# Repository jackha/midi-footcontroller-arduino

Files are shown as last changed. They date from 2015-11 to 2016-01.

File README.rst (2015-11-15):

midi-footcontroller-arduino
---------------------------

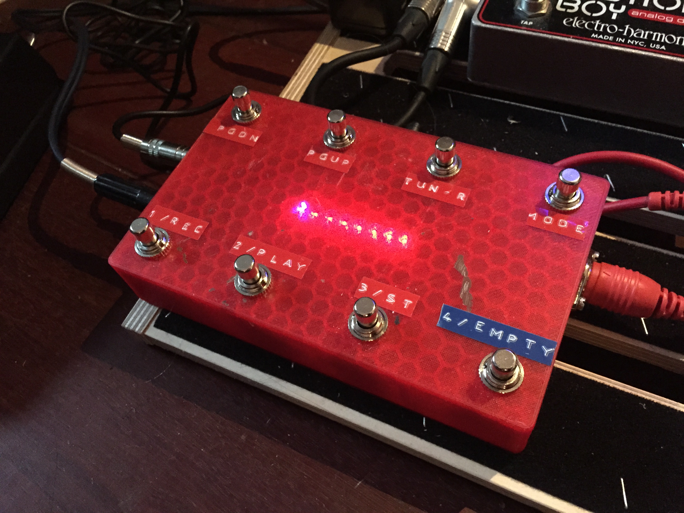
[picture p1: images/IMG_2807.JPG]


License MPL v2.0, originally written by Jack Ha.

I'm using this pedal with an Eventide H9. Awesome fx pedal, but not enough buttons :-)
The foot controller has 2 expression pedal inputs and 8 momentary buttons and was made using an Arduino Uno. 

Preset switching is a pain in the %$#, especially if you also want to tap tempo, adjust volume, use the 'hotknob' as a pedal and use the 'performance' button as well. I know that this is specifically for the H9, but I can imagine you can have the same feeling as well for other gear.

Preset mode:
Page Up, Page Down, Tuner, Mode
Preset 1, Preset 2, Preset 3, Preset 4

Looper mode (didn't use this in the video):
Direction switch, Octave switch, Tuner, Mode
Record, Play, Stop, Empty

media
-----

youtube
=======

https://www.youtube.com/watch?v=iySvyHlC4qQ

https://youtu.be/PKquv8TrxEU

thingiverse
===========

http://www.thingiverse.com/thing:1132912

setup
-----

Make the thing. See Thingiverse.

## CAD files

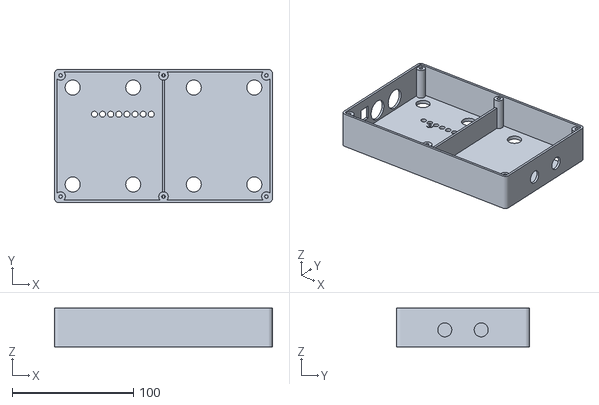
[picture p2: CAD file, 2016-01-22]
openscad/midi-footcontroller-x8.stl
180.0 x 110.0 x 32.0

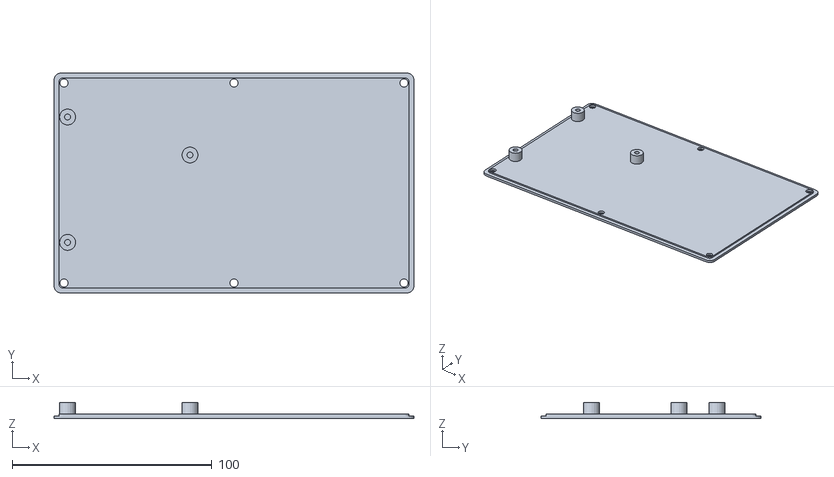
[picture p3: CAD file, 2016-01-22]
openscad/midi-footcontroller-x8-back.stl
180.0 x 110.0 x 8.20

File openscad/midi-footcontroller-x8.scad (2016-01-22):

/*
multiple footswitches, newer version than 'multi-footswitchx'
 
4x2

print with PLA to prevent warping

custom own pcb.
*/

$fn=20;


WALL_THICKNESS = 2;
FRONT_THICKNESS = 3;

BACK_THICKNESS = 1.3;
BACK_THICKNESS_OUTER = 1.0;  // minimum 1

MOUNT_X = 5;
MOUNT_Y = 5;
MOUNT_R_OUTER = 4;
MOUNT_R_INNER = 1.5;

FOOTSWITCH_HOLE_R = 6.25;
FOOTSWITCH_NUM_X = 4;
FOOTSWITCH_NUM_Y = 2;
FOOTSWITCH_SPACING_X = 50;
FOOTSWITCH_SPACING_Y = 80;
FOOTSWITCH_OFFSET_X = 15;
FOOTSWITCH_OFFSET_Y = 15;

WIDTH = 2*FOOTSWITCH_OFFSET_X + (FOOTSWITCH_NUM_X-1)*FOOTSWITCH_SPACING_X;  //180;
HEIGHT = 2*FOOTSWITCH_OFFSET_Y + (FOOTSWITCH_NUM_Y-1)*FOOTSWITCH_SPACING_Y;  // actually depth in our context
DEPTH = 32;  // actually height in our context
ROUNDING_R = 3.5;

PSU_R = 4.1;  // a separate PSU plug
JACK_R = 5.8;

echo("WIDTH:", WIDTH);

// back

//BACK_DEPTH = 3;

module rounded_cube(x, y, z, r) {
	translate([r, r, 0])
	minkowski() {
		cylinder(r=r, h=1);
		cube([x - 2*r, y - 2*r, z-1]);
	}
}



module tapped_hole(r1, r2, h1, h2, h3=5) {
   // make some kind of a funnell
	// for use with screws
	// it is on purpose a little bit bigger than advertised. it is used for subtraction

	translate([0, 0, -1])
	cylinder(r=r1, h=h1+2);
	translate([0, 0, h1])
	cylinder(r1=r1, r2=r2, h=h2+0.1);
	translate([0, 0, h1+h2])
	cylinder(r=r2, h=h3+0.1);
}

module mount_tube(x, y, h1, h2) {
	difference() {
		translate([x, y, h1-0.5])
		cylinder(r=MOUNT_R_OUTER, h=h2-1);

		translate([x, y, h1-1])
		cylinder(r=MOUNT_R_INNER, h=h2);
	}

}

module midi_hole() {
	translate([0,0,-1])
	cylinder(r=8, h=10, $fn=20);
	translate([11.25,0,-1])
	cylinder(r=1.7, h=10, $fn=20);
	translate([-11.25,0,-1])
	cylinder(r=1.7, h=10, $fn=20);
}

module psu_hole() {
	// psu hole
	translate([0,0,-0.1])
	//rotate([-90,0,0])
	//translate([0,0,-0.1])
	cylinder(r=PSU_R, h=10);
}

module jack_hole() {
	// expression pedal
	translate([0,0,-0.1])
	#cylinder(r=JACK_R, h=32);
}

module footswitch_hole() {
	translate([0,0,-0.1])
	#cylinder(r=FOOTSWITCH_HOLE_R, h=22);
	*translate([-6,-11,10])
	#cube([12,30,15]);
}

module mounting_tube(r1=3, r2=1, h=10) {
	difference() {
		cylinder(r=r1, h=h);
		translate([0,0,-0.1])
		cylinder(r=r2, h=h+0.2);
	}
}

module arduino_approx() {
	#cube([67, 53, 20]);
}

module arduino_mount(r1, r2, h) {
	translate([2.5, 18, 0])
	mounting_tube(r1=r1, r2=r2, h=h);

	translate([2.5, 46, 0])
	mounting_tube(r1=r1, r2=r2, h=h);

	translate([53, 3, 0])
	mounting_tube(r1=r1, r2=r2, h=h);

	translate([55, 50, 0])
	mounting_tube(r1=r1, r2=r2, h=h);
}

module pcb_mock() {
    #cube([68,68,22]);

    translate([-10,5.5+10.5,12])
    rotate([0,90,0])
    #cylinder(r=9, h=25);

    translate([-10,29.5+10.5,12])
    rotate([0,90,0])
    #cylinder(r=9, h=25);
    
    translate([-10,53,2])
    #cube([25,10,12]);
}
// the pcb is 68x68mm
module pcb_mount(r1, r2, h) {
    translate([3.3, 3.3, 0])
	mounting_tube(r1=r1, r2=r2, h=h);

	translate([3.3, 66, 0])
	mounting_tube(r1=r1, r2=r2, h=h);

	translate([64.5, 47, 0])
	mounting_tube(r1=r1, r2=r2, h=h);
    
}

module led8_holes() {
	for (i=[0:7]) {
		translate([i*6.7,0,-0.1])
		cylinder(r=2.5, h=10);
	}

	translate([13.5-3.5,-4.1,0.3])
	cylinder(r=1.25,h=10);
	translate([40.5-3.5,-4.1,0.3])
	cylinder(r=1.25,h=10);
}

module led8_mount(r1, r2, h) {
	translate([13.5-3.5,-4.1,0])
	mounting_tube(r1=r1,r2=r2,h=h);
	translate([40.5-3.5,-4.1,0])
	mounting_tube(r1=r1,r2=r2,h=h);
}

module base() {
union() {
	difference() {
		rounded_cube(WIDTH, HEIGHT, DEPTH, ROUNDING_R);

		translate([WALL_THICKNESS, WALL_THICKNESS, FRONT_THICKNESS])
		rounded_cube(
			WIDTH-2*WALL_THICKNESS, HEIGHT-2*WALL_THICKNESS, 
			DEPTH, ROUNDING_R-WALL_THICKNESS);

		for (y=[0:FOOTSWITCH_NUM_Y-1]) {
		for (x=[0:FOOTSWITCH_NUM_X-1]) {
			translate([FOOTSWITCH_OFFSET_X+x*FOOTSWITCH_SPACING_X, FOOTSWITCH_OFFSET_Y+y*FOOTSWITCH_SPACING_Y, -1])
			footswitch_hole();
		}
		}

		*translate([0, 40, 14])
		rotate([90,0,0])
		rotate([0,90,0])
		#midi_hole();

		*translate([0, 40+30, 14])
		rotate([90,0,0])
		rotate([0,90,0])
		#midi_hole();

		*translate([WIDTH/2, HEIGHT, 14])
		rotate([90,0,0])
		psu_hole();

		translate([WIDTH, 40, 14])
		rotate([0,-90,0])
		jack_hole();

		translate([WIDTH, 40+30, 14])
		rotate([0,-90,0])
		jack_hole();

		*translate([55, 28, 5])
		arduino_approx();

		translate([33, 73, 0])
		led8_holes();
	}

	mount_tube(MOUNT_X, MOUNT_Y, FRONT_THICKNESS, DEPTH-FRONT_THICKNESS);
	mount_tube(WIDTH-MOUNT_X, MOUNT_Y, FRONT_THICKNESS, DEPTH-FRONT_THICKNESS);
	mount_tube(MOUNT_X, HEIGHT-MOUNT_Y, FRONT_THICKNESS, DEPTH-FRONT_THICKNESS);
	mount_tube(WIDTH-MOUNT_X, HEIGHT-MOUNT_Y, FRONT_THICKNESS, DEPTH-FRONT_THICKNESS);
	mount_tube(WIDTH/2, MOUNT_Y, FRONT_THICKNESS, DEPTH-FRONT_THICKNESS);
	mount_tube(WIDTH/2, HEIGHT-MOUNT_Y, FRONT_THICKNESS, DEPTH-FRONT_THICKNESS);


	// stronger chassis
	translate([WIDTH/2-WALL_THICKNESS/2,1,1])
	cube([WALL_THICKNESS, HEIGHT-2, DEPTH-10]);

	*translate([135,1,1])
	cube([WALL_THICKNESS, HEIGHT-2, DEPTH-10]);

    translate([33, 73, 0.1])
    led8_mount(3, 1.25, 3.5);

}

}

module base_back() {
	difference() {
		union() {
			translate([0,0, BACK_THICKNESS_OUTER-0.1])
			rounded_cube(WIDTH, HEIGHT, BACK_THICKNESS+0.1, ROUNDING_R);

			translate([WALL_THICKNESS+0.5, WALL_THICKNESS+0.5, 0])
			rounded_cube(WIDTH-2*WALL_THICKNESS-2*0.5, HEIGHT-2*WALL_THICKNESS-2*0.5, BACK_THICKNESS_OUTER+0.1, 2);

		}

		translate([MOUNT_X, MOUNT_Y, 0])
		tapped_hole(r1=2, r2=4, h1=1+BACK_THICKNESS-BACK_THICKNESS_OUTER, h2=2);
		translate([WIDTH-MOUNT_X, MOUNT_Y, 0])
		tapped_hole(r1=2, r2=4, h1=1+BACK_THICKNESS-BACK_THICKNESS_OUTER, h2=2);
		translate([MOUNT_X, HEIGHT-MOUNT_Y, 0])
		tapped_hole(r1=2, r2=4, h1=1+BACK_THICKNESS-BACK_THICKNESS_OUTER, h2=2);
		translate([WIDTH-MOUNT_X, HEIGHT-MOUNT_Y, 0])
		tapped_hole(r1=2, r2=4, h1=1+BACK_THICKNESS-BACK_THICKNESS_OUTER, h2=2);

		translate([WIDTH/2, MOUNT_Y, 0])
		tapped_hole(r1=2, r2=4, h1=1+BACK_THICKNESS-BACK_THICKNESS_OUTER, h2=2);
		translate([WIDTH/2, HEIGHT-MOUNT_Y, 0])
		tapped_hole(r1=2, r2=4, h1=1+BACK_THICKNESS-BACK_THICKNESS_OUTER, h2=2);
	}
}

module back() {
mirror([0,0,1])
//rotate([180,0,0])
base_back();
translate([WALL_THICKNESS+1.5,22,-0.1])
pcb_mount(4, 1.5, 6);

*translate([WALL_THICKNESS+0.5,22,6])
pcb_mock();
}

*difference() {
base();
translate([0, HEIGHT, DEPTH-BACK_THICKNESS+BACK_THICKNESS_OUTER])
rotate([0,180,0])
rotate([0,0,180])
translate([WALL_THICKNESS+0.5,22,6])
pcb_mock();
}

//translate([0, HEIGHT, DEPTH-BACK_THICKNESS+BACK_THICKNESS_OUTER])
//rotate([0,180,0])
//rotate([0,0,180])
back();

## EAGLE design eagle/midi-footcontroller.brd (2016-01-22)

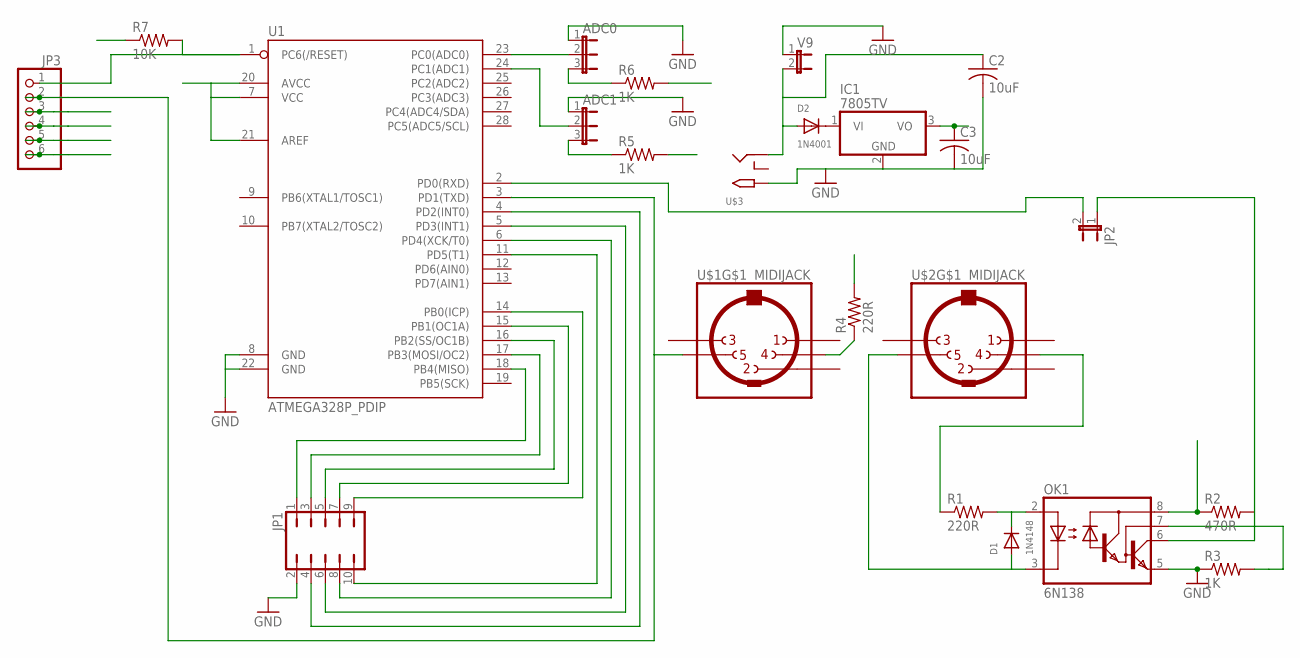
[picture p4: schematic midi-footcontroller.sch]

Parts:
ADC0, ADC1: JP2E; JP2
C2, C3: 10uF; C025-025X050
D1: 1N4148; DO-1N4148
D2: 1N4001; DO-1N4148
IC1: 7805TV; TO220V
JP1: JP5Q
JP2: JP1E; JP1
JP3: PINHD-1X6LOCK; 1X06-BIGLOCK
OK1: 6N138; DIL08
R1, R4: 220R; 0207/9
R2: 470R; 0207/9
R3, R5, R6: 1K; 0207/9
R7: 10K; 0207/9
U1: ATMEGA328P_PDIP; DIL28-3
U$1, U$2: MIDIJACK; CP-2350
U$3: 2.1MMJACKTHM; PJ-102A
V9: JP1E; JP1

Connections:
GND: ADC0.1, ADC1.1, C2.2, C3.2, IC1.2 (GND), JP1.2, JP3.5, OK1.5 (GND), R3.1, U1.8 (GND), U1.22 (GND), U$3.TIP, V9.1
unnamed: D1.C, OK1.2 (A), R1.2
unnamed: D1.A, OK1.3 (C), U$2.5
unnamed: R1.1, U$2.4
unnamed: D2.C, IC1.1 (VI)
unnamed: OK1.7 (VB), R3.2
unnamed: R4.1, U$1.4
unnamed: ADC0.2, U1.23 (PC0(ADC0))
unnamed: JP1.10, U1.11 (PD5(T1))
unnamed: ADC1.2, U1.24 (PC1(ADC1))
unnamed: ADC0.3, R6.1
unnamed: ADC1.3, R5.1
unnamed: JP1.8, U1.6 (PD4(XCK/T0))
unnamed: JP1.6, U1.5 (PD3(INT1))
unnamed: JP1.4, U1.4 (PD2(INT0))
unnamed: JP1.1, U1.18 (PB4(MISO))
unnamed: JP2.1, OK1.6 (VO), R2.2
unnamed: JP1.9, U1.14 (PB0(ICP))
unnamed: JP1.7, U1.15 (PB1(OC1A))
unnamed: JP1.5, U1.16 (PB2(SS/OC1B))
unnamed: JP1.3, U1.17 (PB3(MOSI/OC2))
unnamed: JP3.1, R7.2, U1.1 (PC6(/RESET))
RXD: JP2.2, JP3.3, U1.2 (PD0(RXD))
TXD: JP3.2, U1.3 (PD1(TXD)), U$1.5
V5: C3.1, IC1.3 (VO), JP3.4, OK1.8 (VCC), R2.1, R4.2, R5.2, R6.2, R7.1, U1.7 (VCC), U1.20 (AVCC), U1.21 (AREF)
V9: C2.1, D2.A, U$3.RING, V9.2

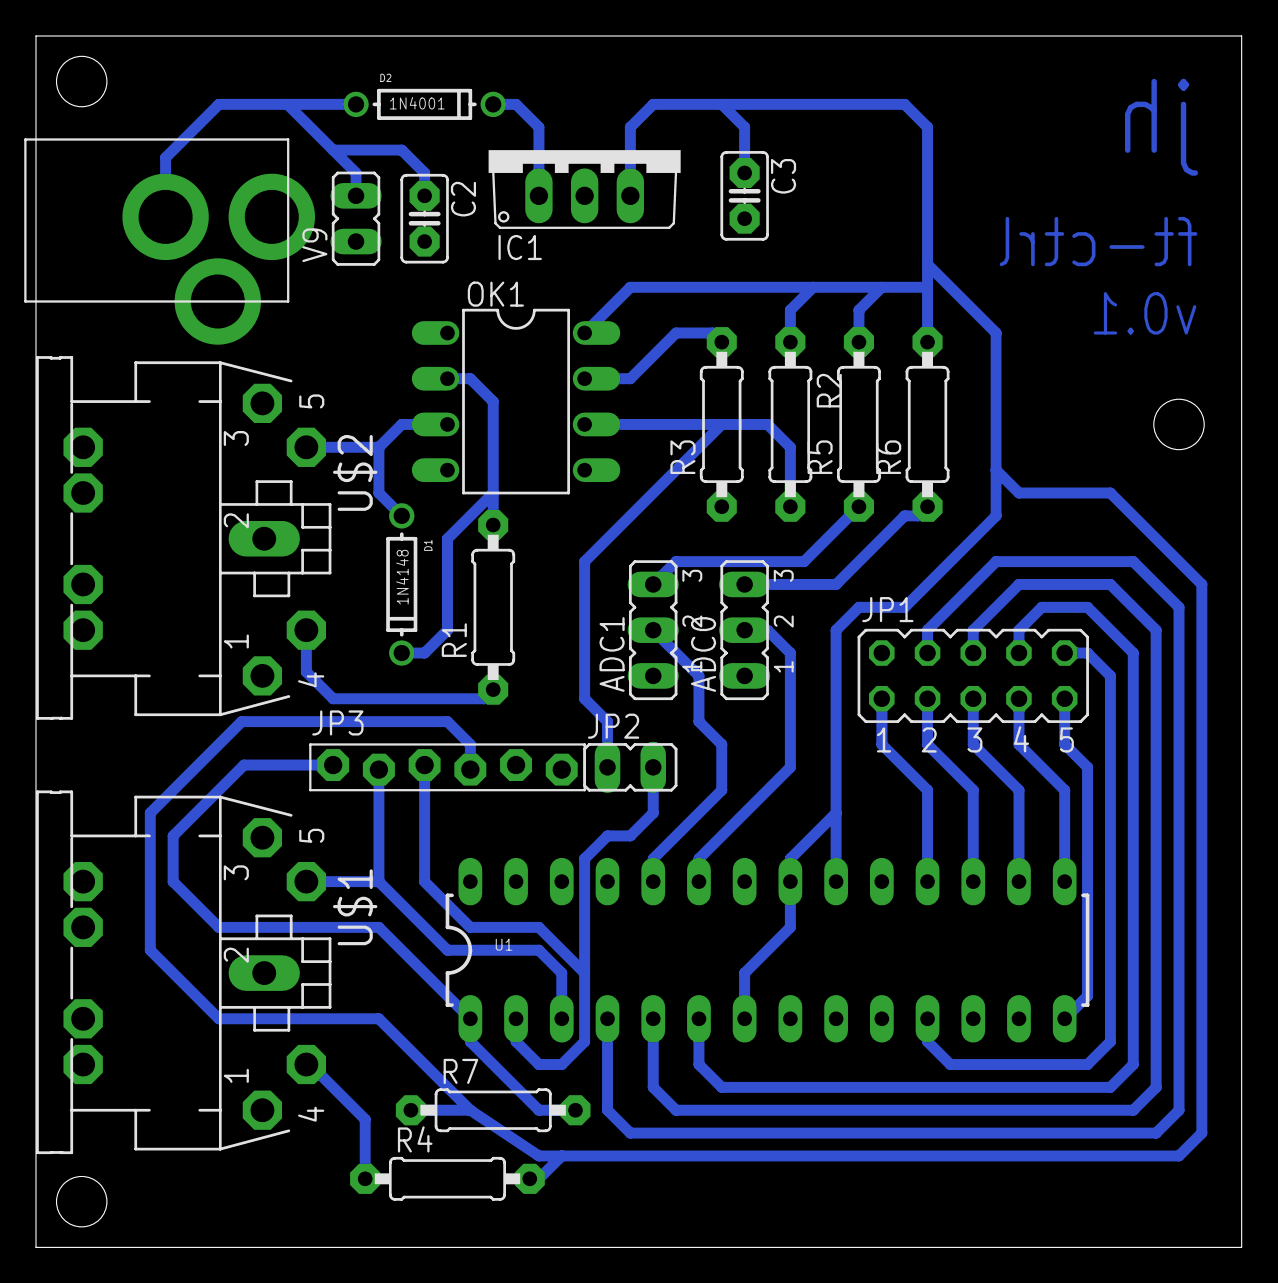
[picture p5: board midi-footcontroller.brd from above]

Board: 2 copper layers, 67.0 x 67.3 mm, 23 parts (0 on the bottom side), 26 nets.

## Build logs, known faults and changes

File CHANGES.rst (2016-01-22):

0.1
---

- First functional version of eagle + arduino code + openscad.

- Lacking some components on pcb to make life easier.

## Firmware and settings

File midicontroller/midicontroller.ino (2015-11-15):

/*
MIDI controller

8 footswitch, 2 expression pedal with 8 neopixel foot controller for Eventide H9.
License MPL v2.0, originally written by Jack Ha.

button numbering:
5 6 7 8
1 2 3 4

8: switch from preset mode to looper mode and vice versa
7: tuner

preset mode
1-4 select 1-4
5,6 page up/down

current bank lights up
press button = all leds light up
expression pedal change = all leds get intensity

looper mode:
1 rec
2 play
3 stop
4 empty

5 direction
6 octave switch

of course, in the code the btn index start at 0.

based on:

 http://www.arduino.cc/en/Tutorial/Midi

from 

https://ccrma.stanford.edu/~craig/articles/linuxmidi/misc/essenmidi.html

   0x80     Note Off
   0x90     Note On
   0xA0     Aftertouch
   0xB0     Continuous controller
   0xC0     Patch change
   0xD0     Channel Pressure
   0xE0     Pitch bend
   0xF0     (non-musical commands)
   
 */
#include <Adafruit_NeoPixel.h>

#define DELAYTIME 20
#define NUM_BUTTONS 8
#define NUM_ANALOGS 2
#define LED 13

#define MIDI_NOTE 0x90
#define MIDI_CC 0xB0
#define MIDI_PC 0xC0
#define MIDI_CC_HIGH_VALUE 0x45

#define MODE_PRESET 1  // fast selection of presets
#define MODE_LOOPER 2  // looper functions
#define MODE_EASY 3  // not implemented

// program Eventide H9 (or any other device) accordingly.
#define MIDI_CC_TUNER 0
#define MIDI_CC_PRESET_START 40  // PRESET_START + index (0 to 3) + 4 * current_page will be sent.
#define MIDI_CC_LOOPER_RECORD 109
#define MIDI_CC_LOOPER_PLAY 110
#define MIDI_CC_LOOPER_STOP 111
#define MIDI_CC_LOOPER_EMPTY 112
#define MIDI_CC_LOOPER_DIRECTION 113
#define MIDI_CC_LOOPER_OCTAVE 114

// buttons!
// looper mode
#define BTN_REC 0
#define BTN_PLAY 1
#define BTN_STOP 2
#define BTN_EMPTY 3
#define BTN_DIRECTION 4
#define BTN_OCTAVE 5

// prset mode
#define BTN_PRESET1 0
#define BTN_PRESET2 1
#define BTN_PRESET3 2
#define BTN_PRESET4 3

#define BTN_PAGE_UP 5
#define BTN_PAGE_DOWN 4

// easy mode
#define BTN_ACTIVE 0
#define BTN_PRESET_DOWN 1
#define BTN_PRESET_UP 2
#define BTN_PERFORMANCE 3

#define BTN_PRESET_DOWN_LOAD 4
#define BTN_PRESET_UP_LOAD 5


#define BTN_TUNER 6
#define BTN_MODE 7

// yes we use an 8 led neopixel! 
#define NEOPIXEL_PIN            6
// How many NeoPixels are attached to the Arduino?
#define NUM_PIXELS      8

// indices for color
#define RED 0
#define GREEN 1
#define BLUE 2

const int button_pin[] = {2,3,4,5, 8,10,9,11};

// looper mode
int button_cmd[] = {MIDI_CC, MIDI_CC, MIDI_CC, MIDI_CC, MIDI_CC, MIDI_CC, MIDI_CC, MIDI_CC};
int button_num[] = {21, 20, 2, 2, 21, 20, 2, 2};

// preset mode

const int analog_pin[] = {A0, A1}; 
int analog_cc[] = {10, 32, 33};  // which cc to send for each analog input

// self-calibrating
int analog_min[] = {1023, 1023};
int analog_max[] = {0, 0};

// When we setup the NeoPixel library, we tell it how many pixels, and which pin to use to send signals.
// Note that for older NeoPixel strips you might need to change the third parameter--see the strandtest
// example for more information on possible values.
Adafruit_NeoPixel pixels = Adafruit_NeoPixel(NUM_PIXELS, NEOPIXEL_PIN, NEO_GRB + NEO_KHZ800);
const int color_button[] = {0,0,30};
const int color_analog[][3] = {{30,0,0},{0,20,0}, {0,10,20}};
int current_colors[NUM_PIXELS][3] = {{0,0,0},{0,0,0},{0,0,0},{0,0,0},{0,0,0},{0,0,0},{0,0,0},{0,0,0}}; 
int last_colors[NUM_PIXELS][3] = {{0,0,0},{0,0,0},{0,0,0},{0,0,0},{0,0,0},{0,0,0},{0,0,0},{0,0,0}};
boolean colors_changed = false;

/* modes etc */

int button_state[] = {0,0,0,0,0,0,0,0};
int button_press[] = {0,0,0,0,0,0,0,0};  // is set for an instant
int button_depress[] = {0,0,0,0,0,0,0,0};  // is set for an instant

long new_state = 0;
long new_value = 0;

int analog_state[] = {0, 0};

int current_mode = MODE_PRESET;  // current bank lights up
int current_page = 0;  // 8 pages because we have 8 leds :-)

boolean have_action = false;


void setup() {
  pixels.begin(); // This initializes the NeoPixel library.
    
  for (int i=0; i<NUM_BUTTONS; i++) {
    pinMode(button_pin[i], INPUT_PULLUP);
  }
  pinMode(LED, OUTPUT);

  //  Set MIDI baud rate:
  Serial.begin(31250);
  //Serial.begin(9600);
}

void loop() {
  // reset colors, we set them at the end of the loop function
  for (int led=0; led<NUM_PIXELS; led++) {
    for (int x=0; x<3; x++) {
      current_colors[led][x] = 0;
    }
  }
  
  // reset changes
  for (int i=0; i<NUM_BUTTONS; i++) {
    button_press[i] = 0;
    button_depress[i] = 0;
  }
  
  // analog inputs
  for (int i=0; i<NUM_ANALOGS; i++) {
    new_state = analogRead(analog_pin[i]);
    if (new_state < analog_min[i]) {
      analog_min[i] = new_state;
//      Serial.println("min=");
//      Serial.println(new_state);
    }
    if (new_state > analog_max[i]) {
      analog_max[i] = new_state;
//      Serial.println("max=");
//      Serial.println(new_state);
    }
    new_value = 128 * (new_state - analog_min[i]) / (analog_max[i] - analog_min[i]);
    if ((abs(analog_state[i] - new_value) > 2) && (analog_max[i] - analog_min[i] > 100)) {  // value changed + check for calibration
//      Serial.print("new value: ");
//      Serial.println(new_value);
//      Serial.println(new_state);
//      Serial.println(analog_max[i]);
//      Serial.println(analog_min[i]);
      // send new cc
      midi_cc(MIDI_CC, analog_cc[i], new_value);
      
//      pixels.show();
      digitalWrite(LED, HIGH);
      //delay(DELAYTIME);
      analog_state[i] = new_value;
    } else {
      digitalWrite(LED, LOW);
    }

    // update led
//    for (int led=0; led<NUM_PIXELS; led++) {
//        if (new_value > led * 16) {
//          current_colors[led][0] += color_analog[i][0];
//          current_colors[led][1] += color_analog[i][1];
//          current_colors[led][2] += color_analog[i][2];
//        } 
//      }
  }
  
  for (int i=0; i<NUM_BUTTONS; i++) {
    new_state = digitalRead(button_pin[i]);
    if ((new_state == LOW) && (button_state[i] != new_state)) {
      button_press[i] = 1;
    }
    if ((new_state == HIGH) && (button_state[i] != new_state)) {
      button_depress[i] = 1;
    }
    button_state[i] = new_state;
  }
    
  // momentary buttons
  have_action = false;
  if (button_press[BTN_MODE]) {
    have_action = true;
    switch (current_mode) {
//      case MODE_EASY: 
//        current_mode = MODE_LOOPER; 
//        break;
      case MODE_PRESET: 
        current_mode = MODE_LOOPER; 
        break;
      case MODE_LOOPER: 
        current_mode = MODE_PRESET; 
        break;
    }
  }
  
  if (button_press[BTN_TUNER]) {
    have_action = true;
    midi_cc(MIDI_CC, MIDI_CC_TUNER, MIDI_CC_HIGH_VALUE);
  }
  if (button_depress[BTN_TUNER]) {
    have_action = true;
    midi_cc(MIDI_CC, MIDI_CC_TUNER, 0x0);
  }
  
  if (current_mode == MODE_PRESET) {
    if (button_press[BTN_PRESET1]) {
      have_action = true;
      midi_cc(MIDI_PC, MIDI_CC_PRESET_START+0+current_page*4, MIDI_CC_HIGH_VALUE);
    }
    if (button_depress[BTN_PRESET1]) {
      have_action = true;
      midi_cc(MIDI_PC, MIDI_CC_PRESET_START+0+current_page*4, 0);
    }

    if (button_press[BTN_PRESET2]) {
      have_action = true;
      midi_cc(MIDI_PC, MIDI_CC_PRESET_START+1+current_page*4, MIDI_CC_HIGH_VALUE);
    }
    if (button_depress[BTN_PRESET2]) {
      have_action = true;
      midi_cc(MIDI_PC, MIDI_CC_PRESET_START+1+current_page*4, 0);
    }

    if (button_press[BTN_PRESET3]) {
      have_action = true;
      midi_cc(MIDI_PC, MIDI_CC_PRESET_START+2+current_page*4, MIDI_CC_HIGH_VALUE);
    }
    if (button_depress[BTN_PRESET3]) {
      have_action = true;
      midi_cc(MIDI_PC, MIDI_CC_PRESET_START+2+current_page*4, 0);
    }

    if (button_press[BTN_PRESET4]) {
      have_action = true;
      midi_cc(MIDI_PC, MIDI_CC_PRESET_START+3+current_page*4, MIDI_CC_HIGH_VALUE);
    }
    if (button_depress[BTN_PRESET4]) {
      have_action = true;
      midi_cc(MIDI_PC, MIDI_CC_PRESET_START+3+current_page*4, 0);
    }

    if (button_press[BTN_PAGE_UP]) {
      have_action = true;
      current_page = (current_page + 1) % 8;
    }
    if (button_press[BTN_PAGE_DOWN]) {
      have_action = true;
      current_page = (current_page + 7) % 8;
    }
  }

  if (current_mode == MODE_LOOPER) {
    if (button_press[BTN_REC]) {
      have_action = true;
      midi_cc(MIDI_CC, MIDI_CC_LOOPER_RECORD, MIDI_CC_HIGH_VALUE);
    }
    if (button_depress[BTN_REC]) {
      have_action = true;
      midi_cc(MIDI_CC, MIDI_CC_LOOPER_RECORD, 0);
    }

    if (button_press[BTN_PLAY]) {
      have_action = true;
      midi_cc(MIDI_CC, MIDI_CC_LOOPER_PLAY, MIDI_CC_HIGH_VALUE);
    }
    if (button_depress[BTN_PLAY]) {
      have_action = true;
      midi_cc(MIDI_CC, MIDI_CC_LOOPER_PLAY, 0);
    }

    if (button_press[BTN_STOP]) {
      have_action = true;
      midi_cc(MIDI_CC, MIDI_CC_LOOPER_STOP, MIDI_CC_HIGH_VALUE);
    }
    if (button_depress[BTN_REC]) {
      have_action = true;
      midi_cc(MIDI_CC, MIDI_CC_LOOPER_STOP, 0);
    }

    if (button_press[BTN_DIRECTION]) {
      have_action = true;
      midi_cc(MIDI_CC, MIDI_CC_LOOPER_DIRECTION, MIDI_CC_HIGH_VALUE);
    }
    if (button_depress[BTN_DIRECTION]) {
      have_action = true;
      midi_cc(MIDI_CC, MIDI_CC_LOOPER_DIRECTION, 0);
    }

    if (button_press[BTN_OCTAVE]) {
      have_action = true;
      midi_cc(MIDI_CC, MIDI_CC_LOOPER_OCTAVE, MIDI_CC_HIGH_VALUE);
    }
    if (button_depress[BTN_OCTAVE]) {
      have_action = true;
      midi_cc(MIDI_CC, MIDI_CC_LOOPER_OCTAVE, 0);
    }
  }
  
  
  /* now the 8 neopixels! */
  
  // analog input status
  /*
  current_colors[4][RED] = analog_state[0]; 
  current_colors[5][RED] = analog_state[0]; 
  current_colors[6][RED] = analog_state[0]; 
  current_colors[7][RED] = analog_state[0]; 
  
  current_colors[0][RED] = analog_state[1]; 
  current_colors[1][RED] = analog_state[1]; 
  current_colors[2][RED] = analog_state[1]; 
  current_colors[3][RED] = analog_state[1]; 
   */
   
  // status
  if (current_mode == MODE_PRESET) {
    // blue glow
    for (int i=0; i<NUM_BUTTONS; i++) {
      current_colors[i][RED] += 2;
      if (button_state[i] == LOW) {
        for (int j=0; j<NUM_BUTTONS; j++) {
          current_colors[j][RED] += 10;
        }
      }
    }
    // current page
    current_colors[current_page][BLUE] += 20; 
  }

  if (current_mode == MODE_LOOPER) {
    // green glow
    for (int i=0; i<NUM_BUTTONS; i++) {
      current_colors[i][GREEN] += 2;
      if (button_state[i] == LOW) {
        for (int j=0; j<NUM_BUTTONS; j++) {
          current_colors[j][GREEN] += 10;
        }
      }    
    }
  }

  /* lazy debouncing */
  if (have_action) {
    delay(DELAYTIME);
  }
  
  /*
  for (int i=0; i<NUM_BUTTONS; i++) {
    new_state = digitalRead(button_pin[i]);

    if ((new_state == LOW) && (button_state[i] != new_state)) {
      midi_cc(button_cmd[i], button_num[i], 0x45);
      digitalWrite(LED, HIGH);
      delay(DELAYTIME);
    }
    if ((new_state == HIGH) && (button_state[i] != new_state)) {
      midi_cc(button_cmd[i], button_num[i], 0x00);
      delay(DELAYTIME);
      digitalWrite(LED, LOW);
    }
    button_state[i] = new_state;

    // check if any leds must be on for button press
    if (new_state == LOW) {
      current_colors[i][0] += color_button[0];
      current_colors[i][1] += color_button[1];
      current_colors[i][2] += color_button[2];
    }
  }
  */
      
         
  // store current pixel settings
  // check if setting pixels is needed 
  colors_changed = false;
  for (int led=0; led<NUM_PIXELS; led++) {
    for (int x=0; x<3; x++) {
      if (last_colors[led][x] != current_colors[led][x]) {
        colors_changed = true;
      }
      last_colors[led][x] = current_colors[led][x];
    }
  }
 
  // set colors if needed
  if (colors_changed) {
    for (int led=0; led<NUM_PIXELS; led++) {
      pixels.setPixelColor(led, pixels.Color(current_colors[led][0],current_colors[led][1],current_colors[led][2])); 
    }
    pixels.show();
  }
  
  delay(1);
}

//  plays a MIDI note.  Doesn't check to see that
//  cmd is greater than 127, or that data values are  less than 127:
void midi_cc(int cmd, int pitch, int velocity) {
  Serial.write(cmd);
  Serial.write(pitch);
  Serial.write(velocity);
}

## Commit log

2016-01-22 added eagle folder
    [midi-footcontroller.brd, midi-footcontroller.sch]
2016-01-22 added all files
    [midi-footcontroller-x8-back.stl, midi-footcontroller-x8.scad, midi-footcontroller-x8.stl]

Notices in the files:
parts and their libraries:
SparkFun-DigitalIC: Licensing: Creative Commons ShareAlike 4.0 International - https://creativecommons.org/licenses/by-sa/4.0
